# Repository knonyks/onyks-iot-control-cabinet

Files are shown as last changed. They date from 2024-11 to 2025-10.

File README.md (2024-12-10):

# Onyks IoT Control Cabinet

## Description

This device is part of the IoT project, which this part functions as locker for the cabins.
The devices is equiped with RFID MIFARE detector which detects student ID cards, it also has Wi-fi and Bletooth connection for database access.

## Features
* Two ways of power supply:
    - Terminal block;
    - DC Jack;
* Access for JTAG I/O ports;
* Access for programmer I/O ports;
* GPIO ports with GND;
* A buzzer turns on when the cabinet opens;
* An external header for an NFC external sensor by SPI transmission;
* An LED diod;
* Boot and Reset buttons;
* An external input for open the lock by e.g an external button;
* A button for opening the lock;
* Two ways of connecting the lock
    - a pin header;
    - terminal block;
* The voltage which is on the lock I/O port is like the power supply input voltage, e.g. when we have 12 V supply we have 12 V on the lock I/O ports;
* M6 screw holes to mounting.

Teorically when we have:
* 12 V, 2A (24 W) power supply we can power the lock which need 12 V and 1.2 A;
* 9 V, 2 A (18 W) power supply we can power the lock which need 9 V and 1 A;
* If the buzzer was replaced with higher voltage buzzer, then the device can operate with 24 V, 1 A (24 W) power supply;

* Used buzzer voltage range : 6 V - 18 V.

### Schematic

[[LINK]](docs/schematics.pdf)

## Images

#### Connection schematic with an external NFC module
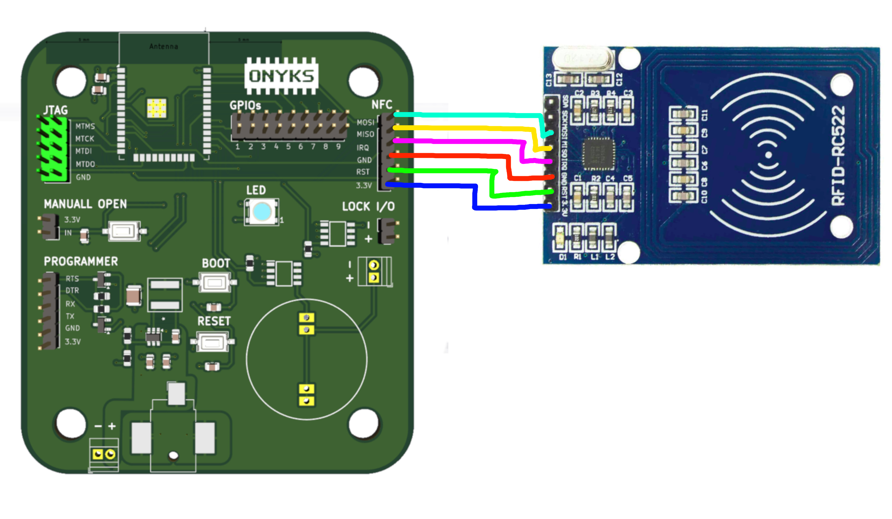
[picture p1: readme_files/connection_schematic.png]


### PCB

#### PCB View
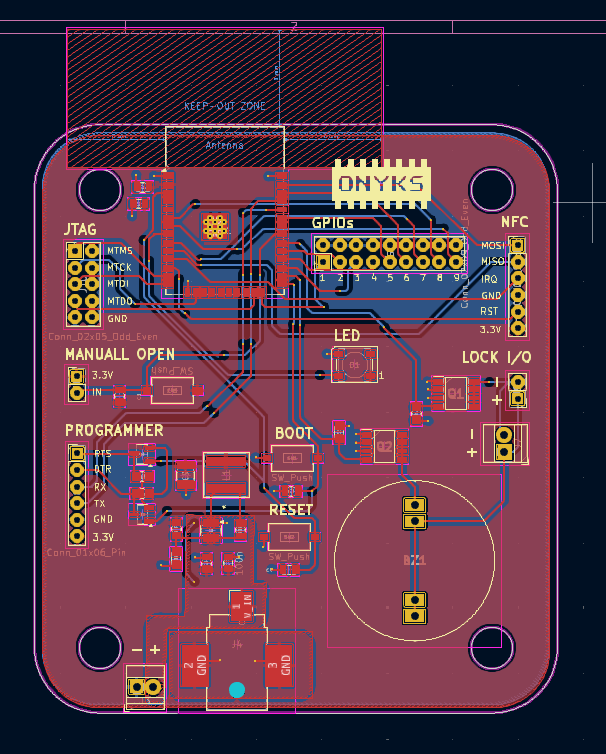
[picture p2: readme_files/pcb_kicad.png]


#### 3D View
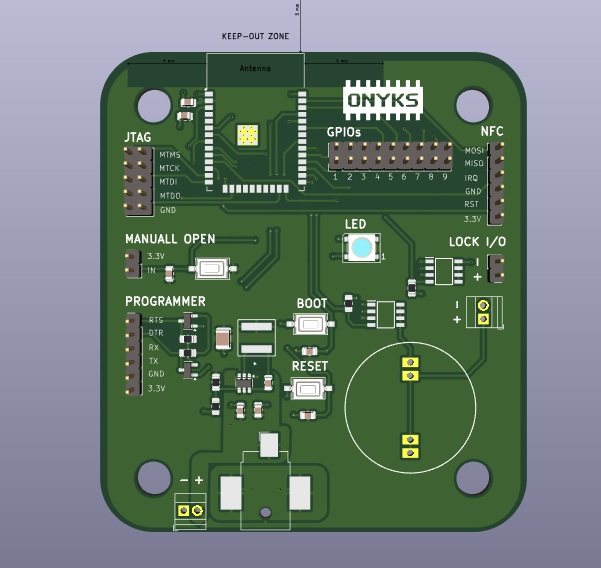
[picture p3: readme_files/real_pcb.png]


## Authors
* Karol Ambroziński
* Jakub Jastrzębski

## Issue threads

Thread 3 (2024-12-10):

Skończone PCB?

zero-jedynkowy, 2024-12-10:
Skończylismy PCB - oddajemy do akceptacji; wyjasnienie PCB jest w README.md.

Koszyk z ,,dzikimi elementami'' - terminal blocki, elementy do przetwornicy, mosfety, buzzer i power jack

 https://www.mouser.pl/ProjectManager/ProjectDetail.aspx?AccessID=6f0a09b32a

----

@zero-jedynkowy  @Xenon02 @przemech

Closed 2025-02-06.

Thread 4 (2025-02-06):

Skończone ale tak naprawde skończone pcb???

zero-jedynkowy, 2025-02-06:
Chyba skończyliśmy ostatecznie?

Poprawiliśmy:
* JTAG jest taki sam w zasadzie jak w ESP PROG (rysunek poniżej)

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
https://docs.espressif.com/projects/esp-iot-solution/en/latest/hw-reference/ESP-Prog_guide.html

* zmiana linii zasilania z poligonu 3.3V na ścieżki - teraz oba poligony na obydwu warstwach są GND
* dodanie rulsów - w drc wyskakują tylko przelotki te od esp
* dodaliśmy wybór zasilania pomiędzy śrubowym a DC jack - jeśli nie zewrzemy ani jacka, ani terminal blocku to możemy z JTAGa zasilanie brać; dzięki zworce nie zewrzemy 3.3V z zasilania z 3.3v JTAGa

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

@przemech @zero-jedynkowy @Xenon02

przemech, 2025-02-10:
Dzięki za informację, dzisiaj sprawdzam i dam znać

przemech, 2025-02-11:
Płytka zdecydowanie zaliczyła duży progres. Proponuję jednakże zrobić spotkanie np. w czwartek? To pokażę jeszcze kilka drobnych problemów.

zero-jedynkowy, 2025-02-17:
Zmiany:
* dodano przelotki na całym PCB;
* zmieniono termal reliefy;
* posprzątano repo.

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

Rulsy:

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

Dodatkowe błędy na dole pod błędami od przelotek z ESP związane z rulsami:
* min. liczbą łącz termicznych.

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

Closed 2025-03-17.

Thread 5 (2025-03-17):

Duże review

przemech, 2025-03-17:
Uniwersalne uwagi - checklist:

- [x] [Hierarchiczna struktura schematu](https://docs.kicad.org/master/en/eeschema/eeschema.html#hierarchical-schematics)
- [x] Global Label -> Net Label (lokalne)
- [x] Global Label -> Hierarchical Label (między schematami)
- [x] No Connect Flags dla niepodłączoncych pinów
- [x] Czytanie schematów od lewej do prawej -> np. zasilanie po lewej i odbiorca po prawej
- [x] Zbyt dokładne wartości elementów (zbyt dokładny szereg)
- [x] Nazwa modelu cewki do symbolu  jako kolejny field
- [x] Napięcia przy kondensatorach np. 10u -> 10n/10V
- [x] Obudowy SMD 0603 (ew. dla kondesnatorów o dużych pojemnościach 0805)
- [x] Przy złączu zasilania opis zakresu napięcia i maksymalny prąd

Do tego projektu:

Schemat:
- [x] Uporządkowanie wyprowadzeń do innych schematów
- [x] Do wydzielenia poszczególne części (dioda WS2018B, lock, buzzer...)
- [x] wszystko z programowania w jednym miejscu (może nawet razem z ESP32)
- [x] NFC connector nie w schemacie power supply
- [x] Niesprecyzowany model przetwornicy (PFM a FPWM)
- [x] Jaki dokładnie model przetwornicy i dlaczego (do napisania w schemacie)?
    - w jakim trybie
    - jak ten tryb działa
    - wyłączanie - efekt ripple
    - zaznaczyć, że tryb PFM
    - do zweryfikowania prądy na schemacie
    - napisać ile prądu w trybach pracy
- [x] Kondensatory 10V
- [x] Kondesantory 100n - 50V
- [x] Kondensator 100u - bardzo duży - na schemacie nie jest to symbol elektrolitycznego
- [x] Przyciski jak SW3, które mają pracować w trybie z pull-down - do napisania, że będą tak pracować -> informacja dla programisty mikrokontrolera
- [x] MOSFET do sprawdzenia na prądy

PCB:
- [ ] Podkładki pod otwory będą zachaczać o elementy
- [ ] Do przeanalizowania rozmieszczenie elementów i routing

przemech, 2025-04-03:
Zamek zamontowany jest w szafie - możemy zmierzyć prąd zamka w poniedziałek.

Closed 2025-07-15.

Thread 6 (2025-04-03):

Otwory montażowe na schemacie

przemech, 2025-04-03:
Na schemacie jest tak:

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

Nie trzeba dodawać tego do schematu, bo to jest tam niepotrzebne.

Można dodać to bezpośrednio w PCB:
- Jako VIA

albo

- `Place` > `Place Footprints` > `MountingHole_3.2mm_M3_DIN965_Pad_TopBottom`.

Później trzeba wejść w ustawienia padów (górnej oraz dolnej warstwy):

- `Pad Properties` > `General` > `Net name`: `GND` x2

Dodatkowo można wyłączyć "clearance" w ustawieniach footprinta:

- `Footprint Properties` > `Clearance Overrides and Settings` > `Pad connection to zones:` > `Solid`

Wygląda to wtedy tak:

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

Xenon02, 2025-04-04:
Tylko to czy jeszcze jakieś zmiany ?

Robiłem tak, bo w robocie w sumie robili podobnie, ale nie ma problemu to zmienić.

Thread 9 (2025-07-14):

Review

przemech, 2025-07-14:
- [x] Kąty ostre, przykłady:

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

- [x] Połączenie goldpinu do warstwy zasilania do poprawy - za cienkie, a przecież ścieżka jest znacznie grubsza:

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

- [x] C11 i C10 do zamiany miejscami i na schemacie i na PCB - mniejsza pojemność bliżej MCU

Closed 2025-07-15.

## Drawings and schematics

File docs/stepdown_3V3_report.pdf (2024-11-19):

## WEBENCH ® Design Report

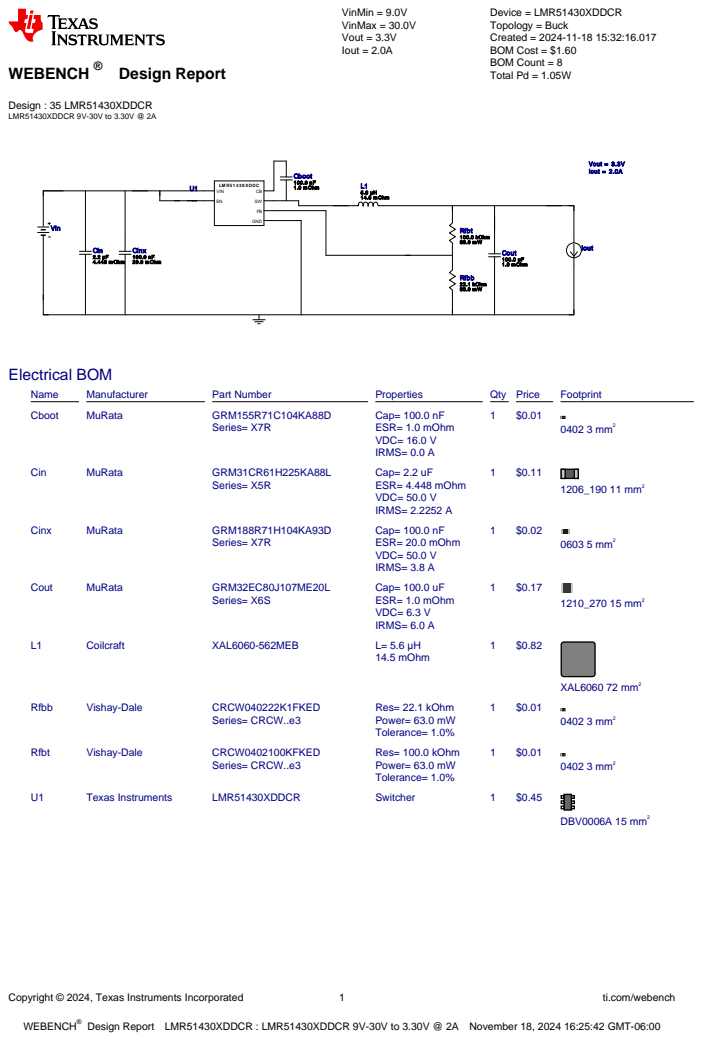
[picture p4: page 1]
Copyright © 2024, Texas Instruments Incorporated; ti.com/webench; WEBENCH®; Design : 35 LMR51430XDDCR LMR51430XDDCR 9V-30V to 3.30V @ 2A; VinMin = 9.0V VinMax = 30.0V Vout = 3.3V Iout = 2.0A; Device = LMR51430XDDCR Topology = Buck Created = 2024-11-18 15:32:16.017 BOM Cost = $1.60 BOM Count = 8 Total Pd = 1.05W; Cin 2.2 µF 4.448 m Ohm; LM R5 1 4 3 0 XDDC; GND; VIN; Cout 100.0 µF 1.0 m Ohm; Cinx 100.0 nF 20.0 m Ohm; L1 5.6 µH 14.5 m Ohm; Rfbb 22.1 kOhm 63.0 m W; Rfbt 100.0 kOhm 63.0 m W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

Design Report LMR51430XDDCR : LMR51430XDDCR 9V-30V to 3.30V @ 2A November 18, 2024 16:25:42 GMT-06:00

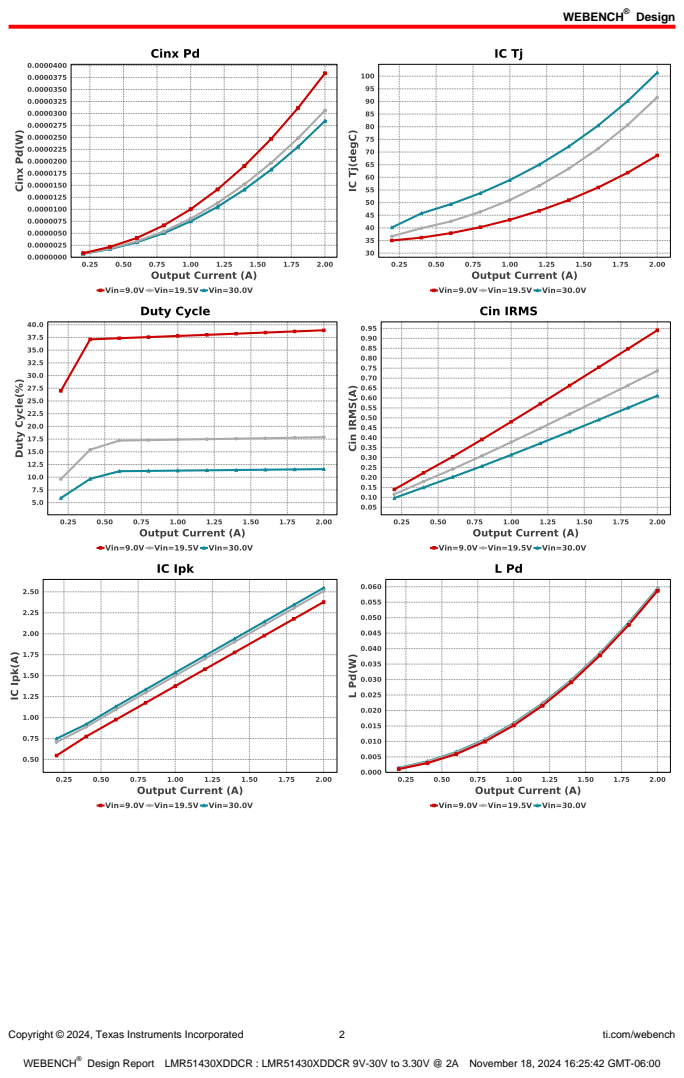
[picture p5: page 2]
Design; Copyright © 2024, Texas Instruments Incorporated; ti.com/webench

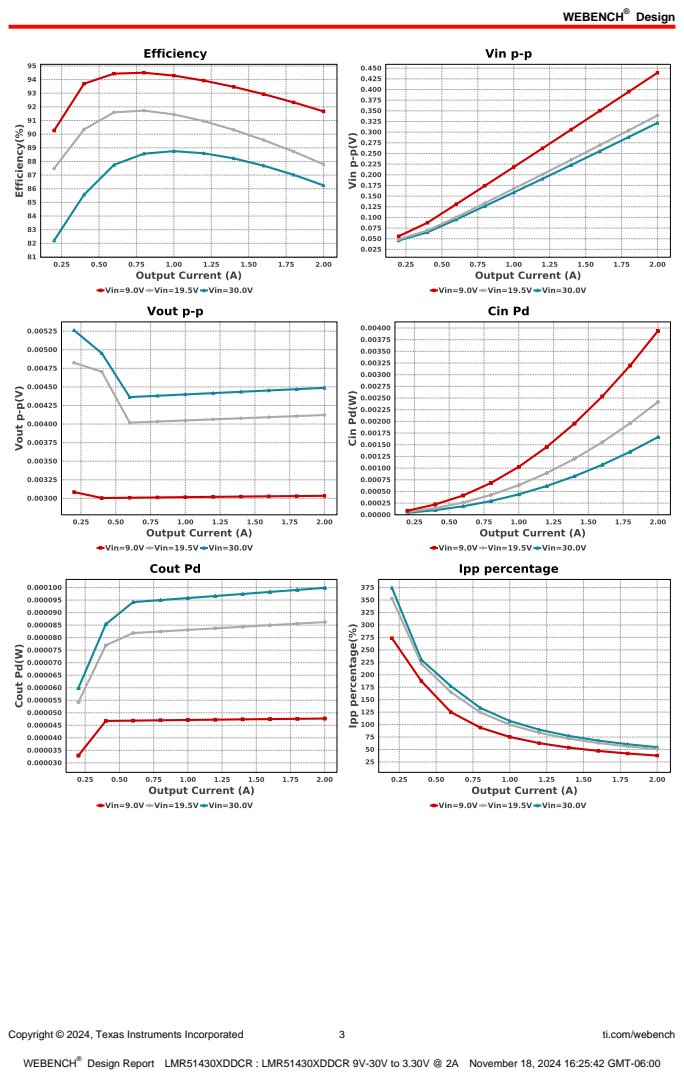
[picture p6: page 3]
Copyright © 2024, Texas Instruments Incorporated; ti.com/webench

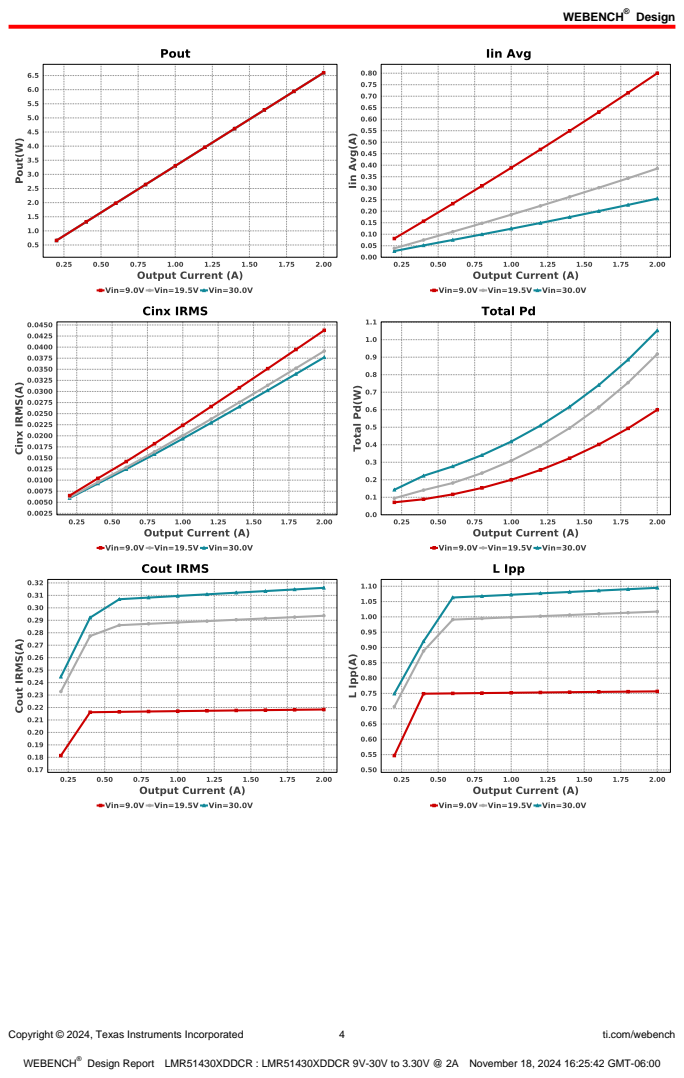
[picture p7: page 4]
Copyright © 2024, Texas Instruments Incorporated; ti.com/webench

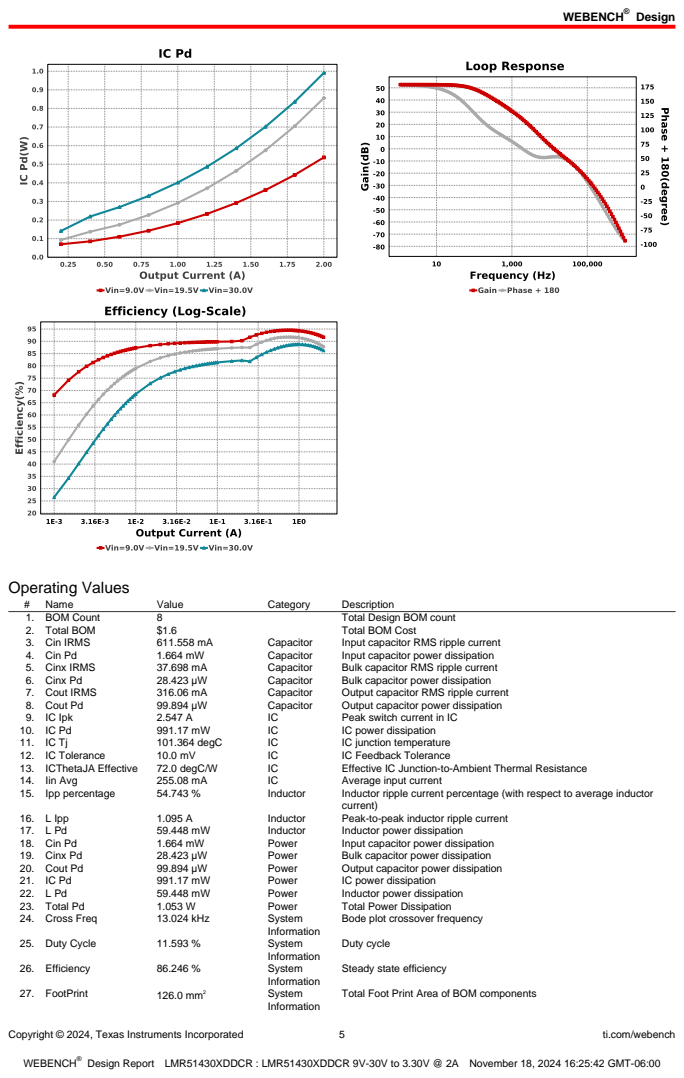
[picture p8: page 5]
Copyright © 2024, Texas Instruments Incorporated; ti.com/webench; Operating Values; Name; Value; Category; Description; 1. BOM Count; Total Design BOM count; 2. Total BOM; Total BOM Cost; 3. Cin IRMS; Capacitor; Input capacitor RMS ripple current; 4. Cin Pd; Input capacitor power dissipation; 5. Cinx IRMS; Bulk capacitor RMS ripple current; 6. Cinx Pd; Bulk capacitor power dissipation; 7. Cout IRMS; Output capacitor RMS ripple current; 8. Cout Pd; Output capacitor power dissipation; 9. IC Ipk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

Bode plot crossover frequency

Steady state efficiency

Total Foot Print Area of BOM components

Copyright © 2024, Texas Instruments Incorporated | 6 | ti.com/webench
# | Name | Value | Category | Description

28. Frequency | 500.0 kHz | System
| | | Information | Switching frequency
29. Gain Marg | -28.074 dB | System
| | | Information | Bode Plot Gain Margin
30. Iout | 2.0 A | System
| | | Information | Iout operating point
31. Low Freq Gain | 52.592 dB | System
| | | Information | Gain at 1Hz
32. Mode | CCM | System
| | | Information | Conduction Mode
33. Phase Marg | 53.292 deg | System
| | | Information | Bode Plot Phase Margin
34. Pout | 6.6 W | System
| | | Information | Total output power
35. Vin | 30.0 V | System
| | | Information | Vin operating point
36. Vin p-p | 321.692 mV | System
| | | Information | Peak-to-peak input voltage
37. Vout | 3.3 V | System
| | | Information | Operational Output Voltage
38. Vout Actual | 3.315 V | System
| | | Information | Vout Actual calculated based on selected voltage divider resistors
39. Vout Tolerance | 3.349 % | System
| | | Information | Vout Tolerance based on IC Tolerance (no load) and voltage divider resistors if applicable
40. Vout p-p | 4.488 mV | System
| | | Information | Peak-to-peak output ripple voltage

## Design Inputs

Name | Value | Description
Iout | 2.0 | Maximum Output Current
VinMax | 30.0 | Maximum input voltage
VinMin | 9.0 | Minimum input voltage
Vout | 3.3 | Output Voltage
| base_pn | | LMR51430X | Base Product Number
source | DC | Input Source Type
Ta | 30.0 | Ambient temperature


Copyright © 2024, Texas Instruments Incorporated | 7 | ti.com/webench

## Assembly

## Component Testing

Some published data on components in datasheets such as Capacitor ESR and Inductor DC resistance is based on conservative values that will guarantee that the components always exceed the specification. For design purposes it is usually better to work with typical values. Since this data is not always available it is a good practice to measure the Capacitance and ESR values of Cin and Cout, and the inductance and DC resistance of L1 before assembly of the board. Any large discrepancies in values should be electrically simulated in WEBENCH to check for instabilities and thermally simulated in WebTHERM to make sure critical temperatures are not exceeded.
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

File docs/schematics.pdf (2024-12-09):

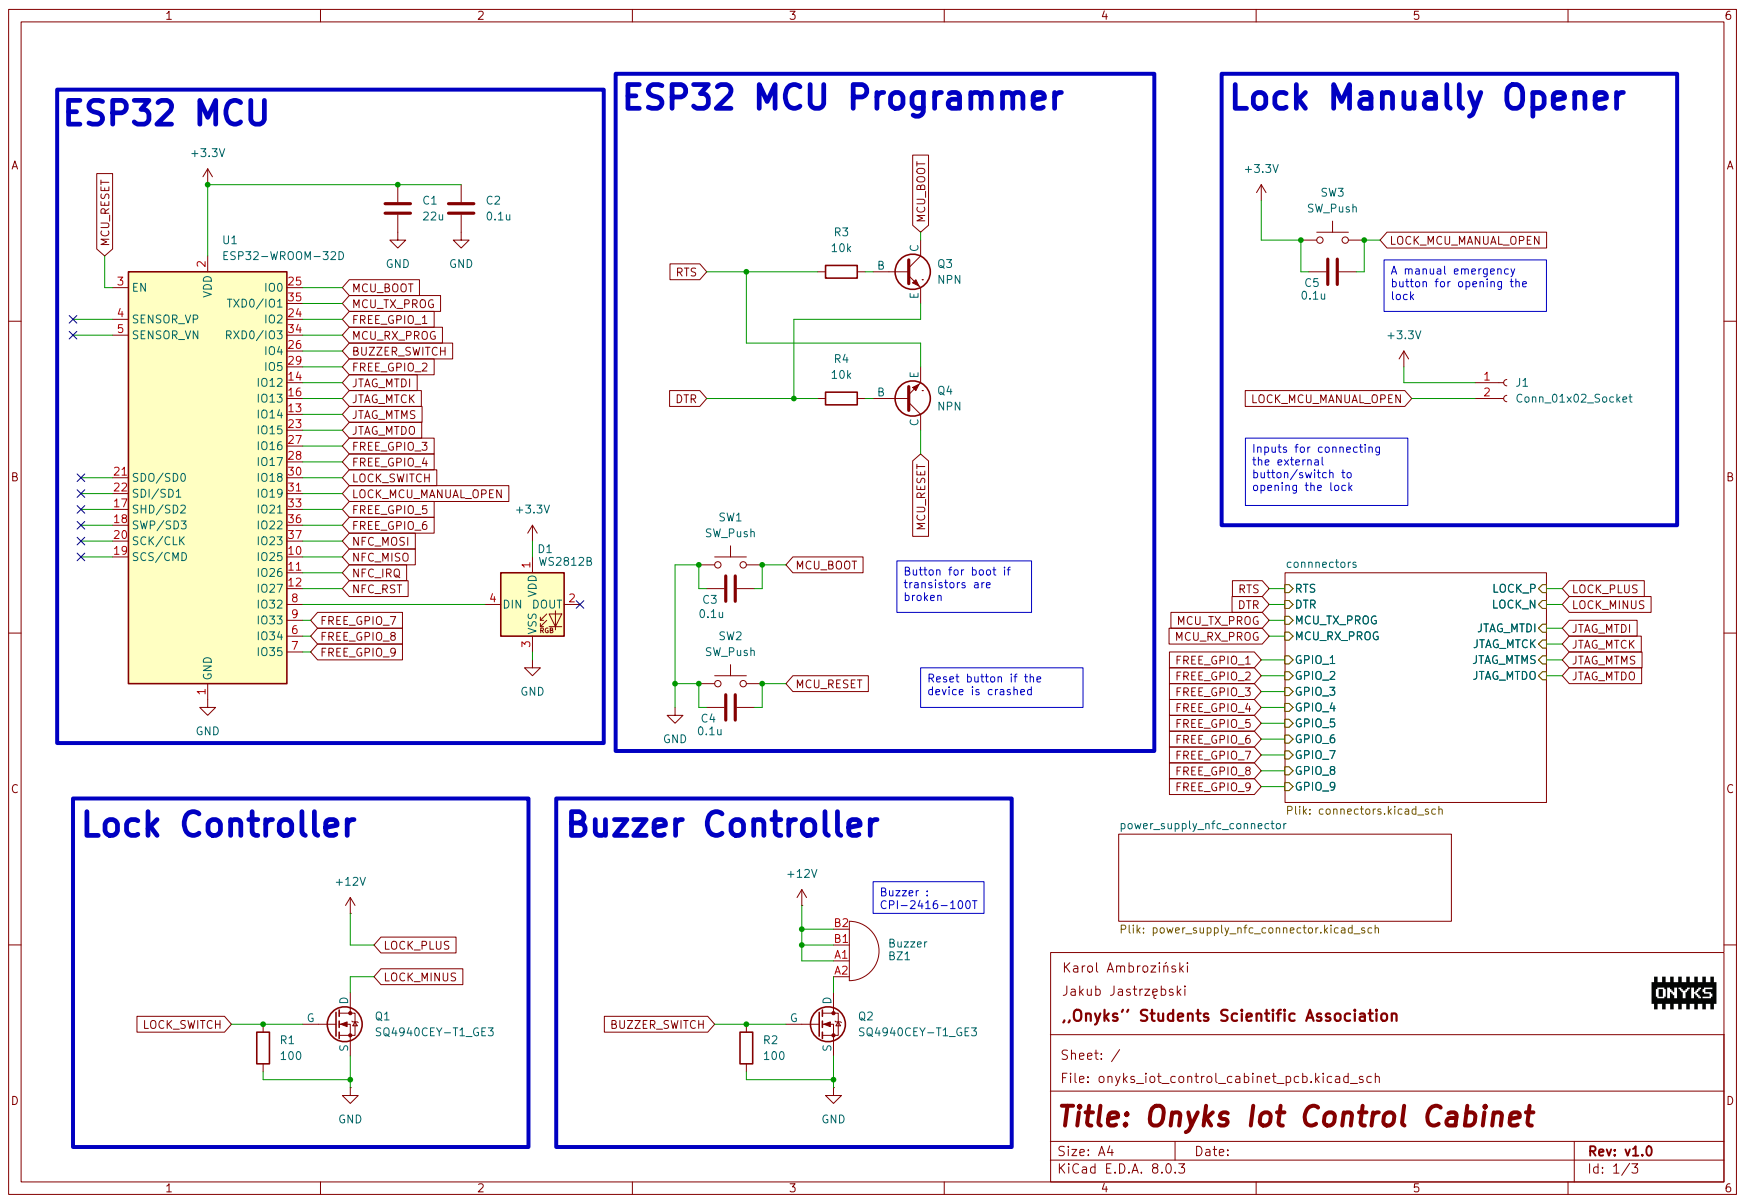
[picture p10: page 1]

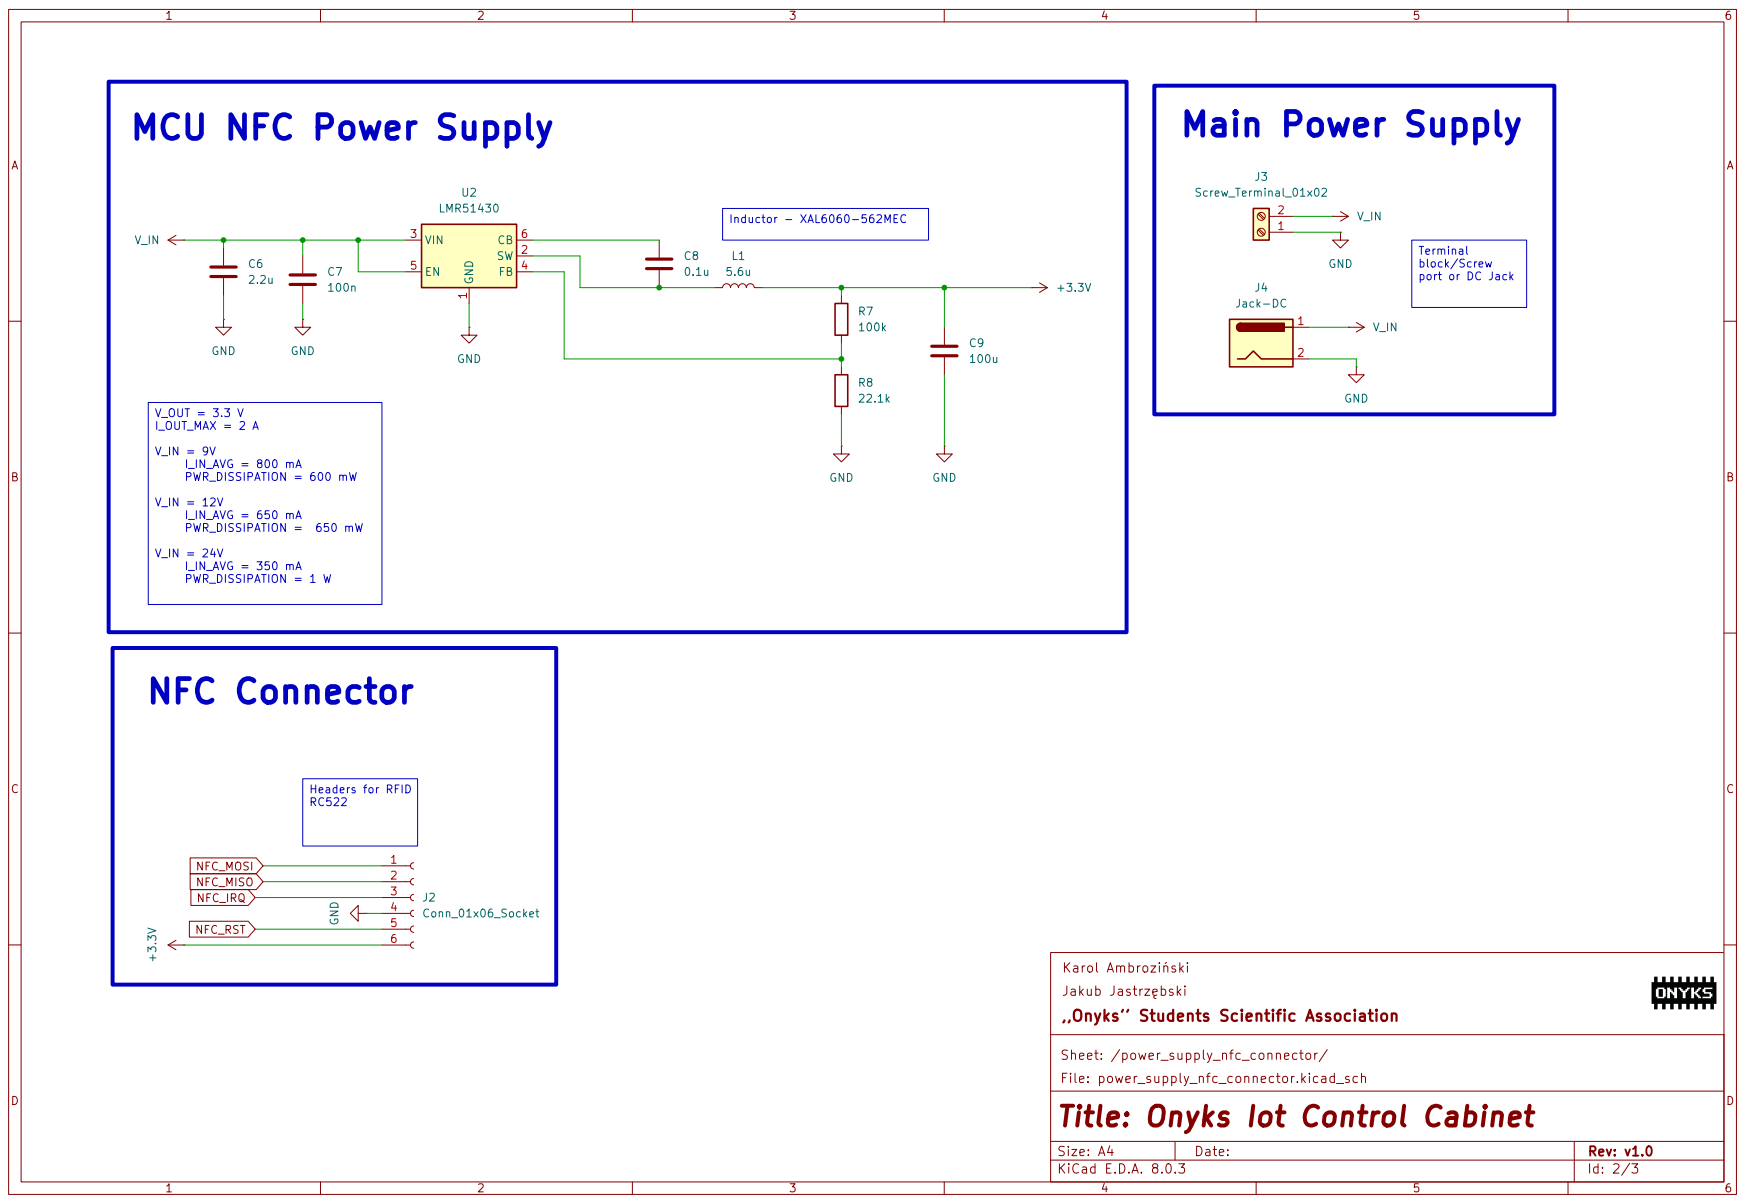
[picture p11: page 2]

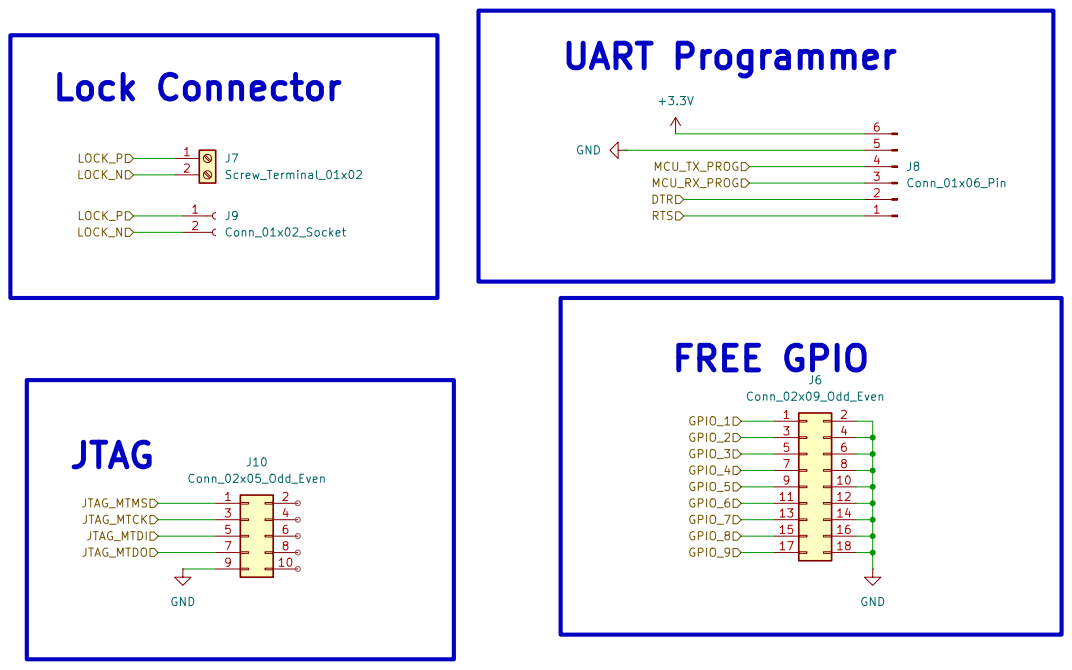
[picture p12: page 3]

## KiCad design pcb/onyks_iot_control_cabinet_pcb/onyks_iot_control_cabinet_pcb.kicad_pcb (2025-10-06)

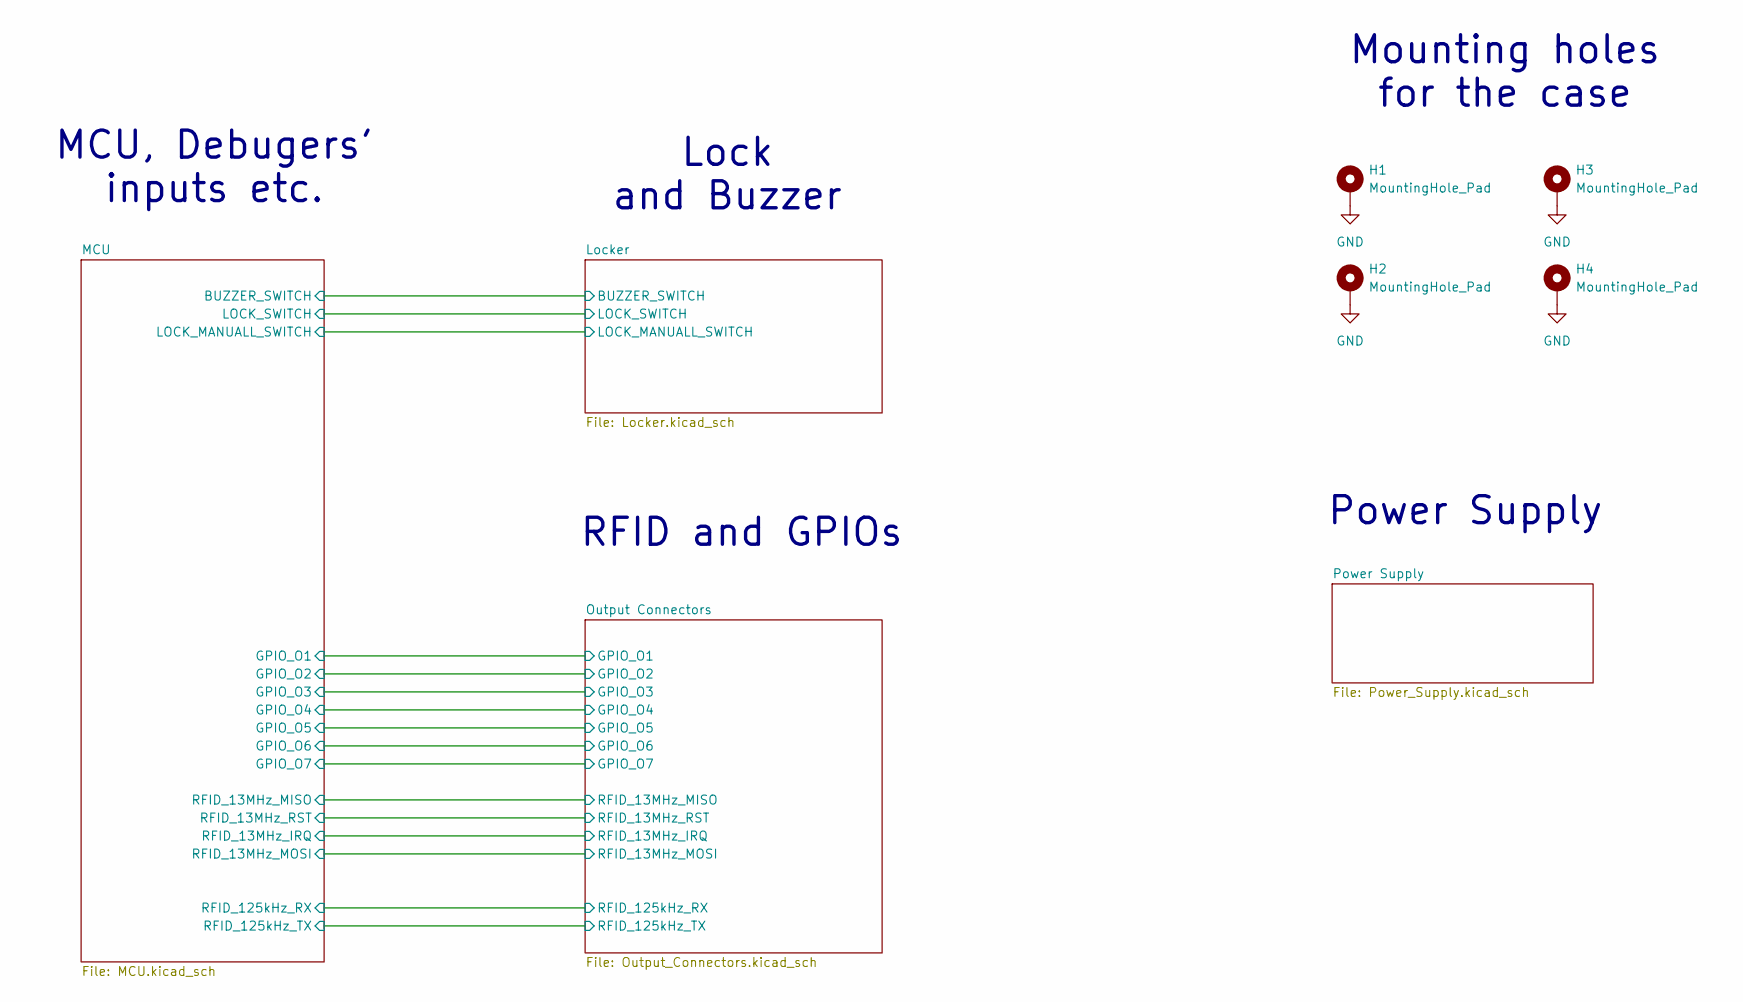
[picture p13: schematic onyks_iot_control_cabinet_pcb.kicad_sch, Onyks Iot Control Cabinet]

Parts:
H1, H2, H3, H4: MountingHole_Pad; MountingHole_3.2mm_M3_DIN965_Pad_TopBottom

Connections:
GND: H1.1, H2.1, H3.1, H4.1; also elsewhere on the board

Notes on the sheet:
Power Supply
RFID and GPIOs
Mounting holes for the case
MCU, Debugers' inputs etc.
Lock and Buzzer

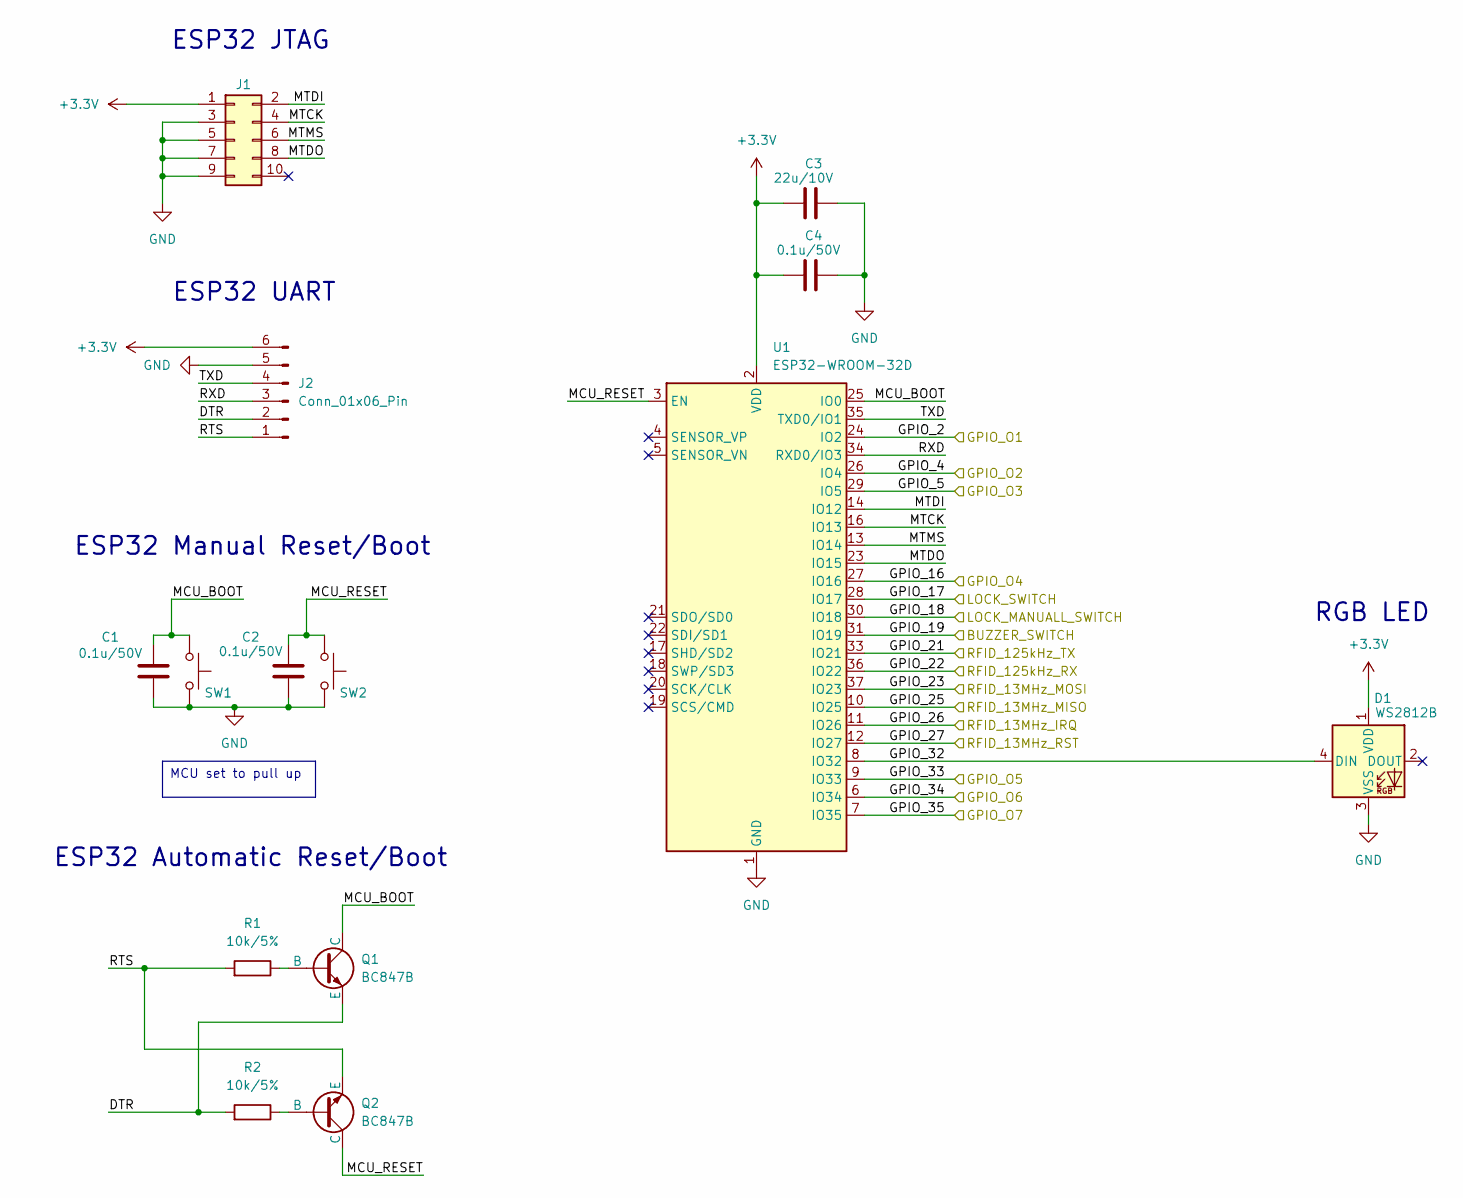
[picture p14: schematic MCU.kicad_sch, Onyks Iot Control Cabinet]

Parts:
C1, C2, C4: 0.1u/50V; C_0603_1608Metric
C3: 22u/10V; C_0603_1608Metric
D1: WS2812B; LED_WS2812B_PLCC4_5.0x5.0mm_P3.2mm
J1: Conn_02x05_Odd_Even; PinHeader_2x05_P2.54mm_Vertical
J2: Conn_01x06_Pin; PinHeader_1x06_P2.54mm_Vertical
Q1, Q2: BC847B; SOT-23-3
R1, R2: 10k/5%; R_0805_2012Metric_Pad1.20x1.40mm_HandSolder
SW1, SW2: SW_Push; SW_Tactile_SPST_NO_Straight_CK_PTS636Sx25SMTRLFS
U1: ESP32-WROOM-32D

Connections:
+3.3V: C3.1, C4.1, D1.1 (VDD), J1.1, J2.6, U1.2 (VDD); also elsewhere on the board
/MCU/DTR: J2.2, Q1.3 (E), R2.2
/MCU/GPIO_2: U1.24 (IO2); also elsewhere on the board
/MCU/GPIO_4: U1.26 (IO4); also elsewhere on the board
/MCU/GPIO_5: U1.29 (IO5); also elsewhere on the board
/MCU/GPIO_16: U1.27 (IO16); also elsewhere on the board
/MCU/GPIO_17: U1.28 (IO17); also elsewhere on the board
/MCU/GPIO_18: U1.30 (IO18); also elsewhere on the board
/MCU/GPIO_19: U1.31 (IO19); also elsewhere on the board
/MCU/GPIO_21: U1.33 (IO21); also elsewhere on the board
/MCU/GPIO_22: U1.36 (IO22); also elsewhere on the board
/MCU/GPIO_23: U1.37 (IO23); also elsewhere on the board
/MCU/GPIO_25: U1.10 (IO25); also elsewhere on the board
/MCU/GPIO_26: U1.11 (IO26); also elsewhere on the board
/MCU/GPIO_27: U1.12 (IO27); also elsewhere on the board
/MCU/GPIO_32: D1.4 (DIN), U1.8 (IO32)
/MCU/GPIO_33: U1.9 (IO33); also elsewhere on the board
/MCU/GPIO_34: U1.6 (IO34); also elsewhere on the board
/MCU/GPIO_35: U1.7 (IO35); also elsewhere on the board
/MCU/MCU_BOOT: C1.1, Q1.1 (C), SW1.1, U1.25 (IO0)
/MCU/MCU_RESET: C2.1, Q2.1 (C), SW2.1, U1.3 (EN)
/MCU/MTCK: J1.4, U1.16 (IO13)
/MCU/MTDI: J1.2, U1.14 (IO12)
/MCU/MTDO: J1.8, U1.23 (IO15)
/MCU/MTMS: J1.6, U1.13 (IO14)
/MCU/RTS: J2.1, Q2.3 (E), R1.2
/MCU/RXD: J2.3, U1.34 (RXD0/IO3)
/MCU/TXD: J2.4, U1.35 (TXD0/IO1)
GND: C1.2, C2.2, C3.2, C4.2, D1.3 (VSS), J1.3, J1.5, J1.7, J1.9, J2.5, SW1.2, SW2.2, U1.1 (GND), U1.15 (GND), U1.38 (GND), U1.39 (GND); also elsewhere on the board
unnamed: Q1.2 (B), R1.1
unnamed: Q2.2 (B), R2.1

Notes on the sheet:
ESP32 UART
RGB LED
ESP32 Automatic Reset/Boot
ESP32 Manual Reset/Boot
ESP32 JTAG
MCU set to pull up

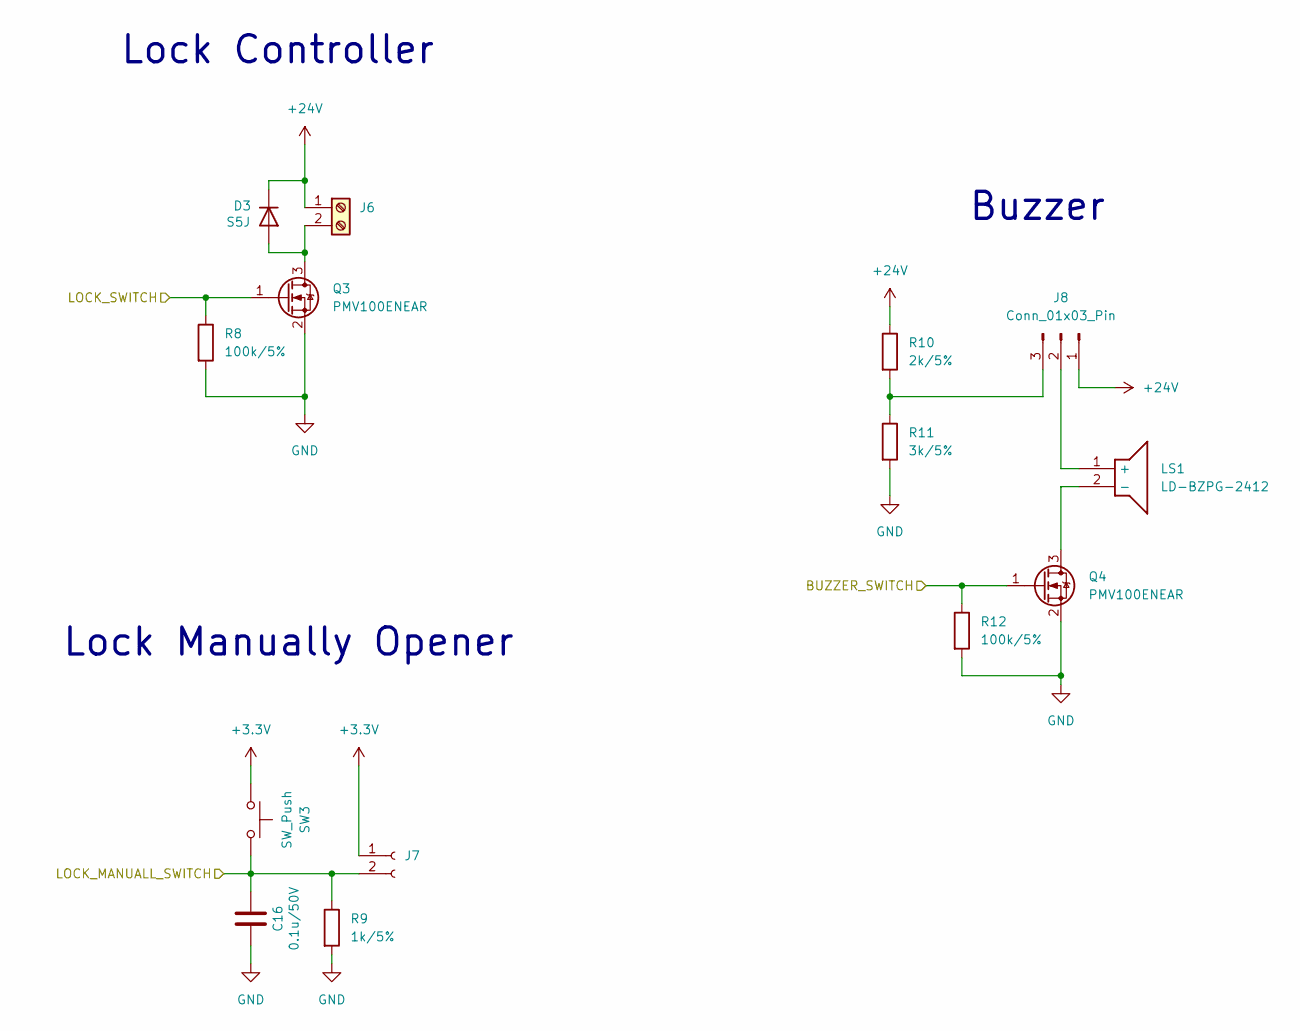
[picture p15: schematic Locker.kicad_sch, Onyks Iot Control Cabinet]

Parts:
C16: 0.1u/50V; C_0603_1608Metric
D3: S5J; D_SMC
J6: Screw_Terminal_01x02; TerminalBlock_Altech_AK300-2_P5.00mm
J7: Conn_01x02_Socket; PinHeader_1x02_P2.54mm_Vertical
J8: Conn_01x03_Pin; PinHeader_1x03_P2.54mm_Vertical
LS1: LD-BZPG-2412; LDBZPG2412; Manufacturer_Part_Number LD-BZPG-2412
Q3, Q4: PMV100ENEAR; SOT-23
R8, R12: 100k/5%; R_0805_2012Metric_Pad1.20x1.40mm_HandSolder
R9: 1k/5%; R_0805_2012Metric_Pad1.20x1.40mm_HandSolder
R10: 2k/5%; R_0805_2012Metric_Pad1.20x1.40mm_HandSolder
R11: 3k/5%; R_0805_2012Metric_Pad1.20x1.40mm_HandSolder
SW3: SW_Push; SW_Tactile_SPST_NO_Straight_CK_PTS636Sx25SMTRLFS

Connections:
+3.3V: J7.1, SW3.1; also elsewhere on the board
+24V: D3.1 (K), J6.1, J8.1, R10.1; also elsewhere on the board
/MCU/GPIO_17: Q3.1 (G), R8.1; also elsewhere on the board
/MCU/GPIO_18: C16.1, J7.2, R9.1, SW3.2; also elsewhere on the board
/MCU/GPIO_19: Q4.1 (G), R12.1; also elsewhere on the board
GND: C16.2, Q3.2 (S), Q4.2 (S), R8.2, R9.2, R11.2, R12.2; also elsewhere on the board
unnamed: D3.2 (A), J6.2, Q3.3 (D)
unnamed: J8.2, LS1.1 (+)
unnamed: J8.3, R10.2, R11.1
unnamed: LS1.2 (-), Q4.3 (D)

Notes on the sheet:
Lock Manually Opener
Lock Controller
Buzzer

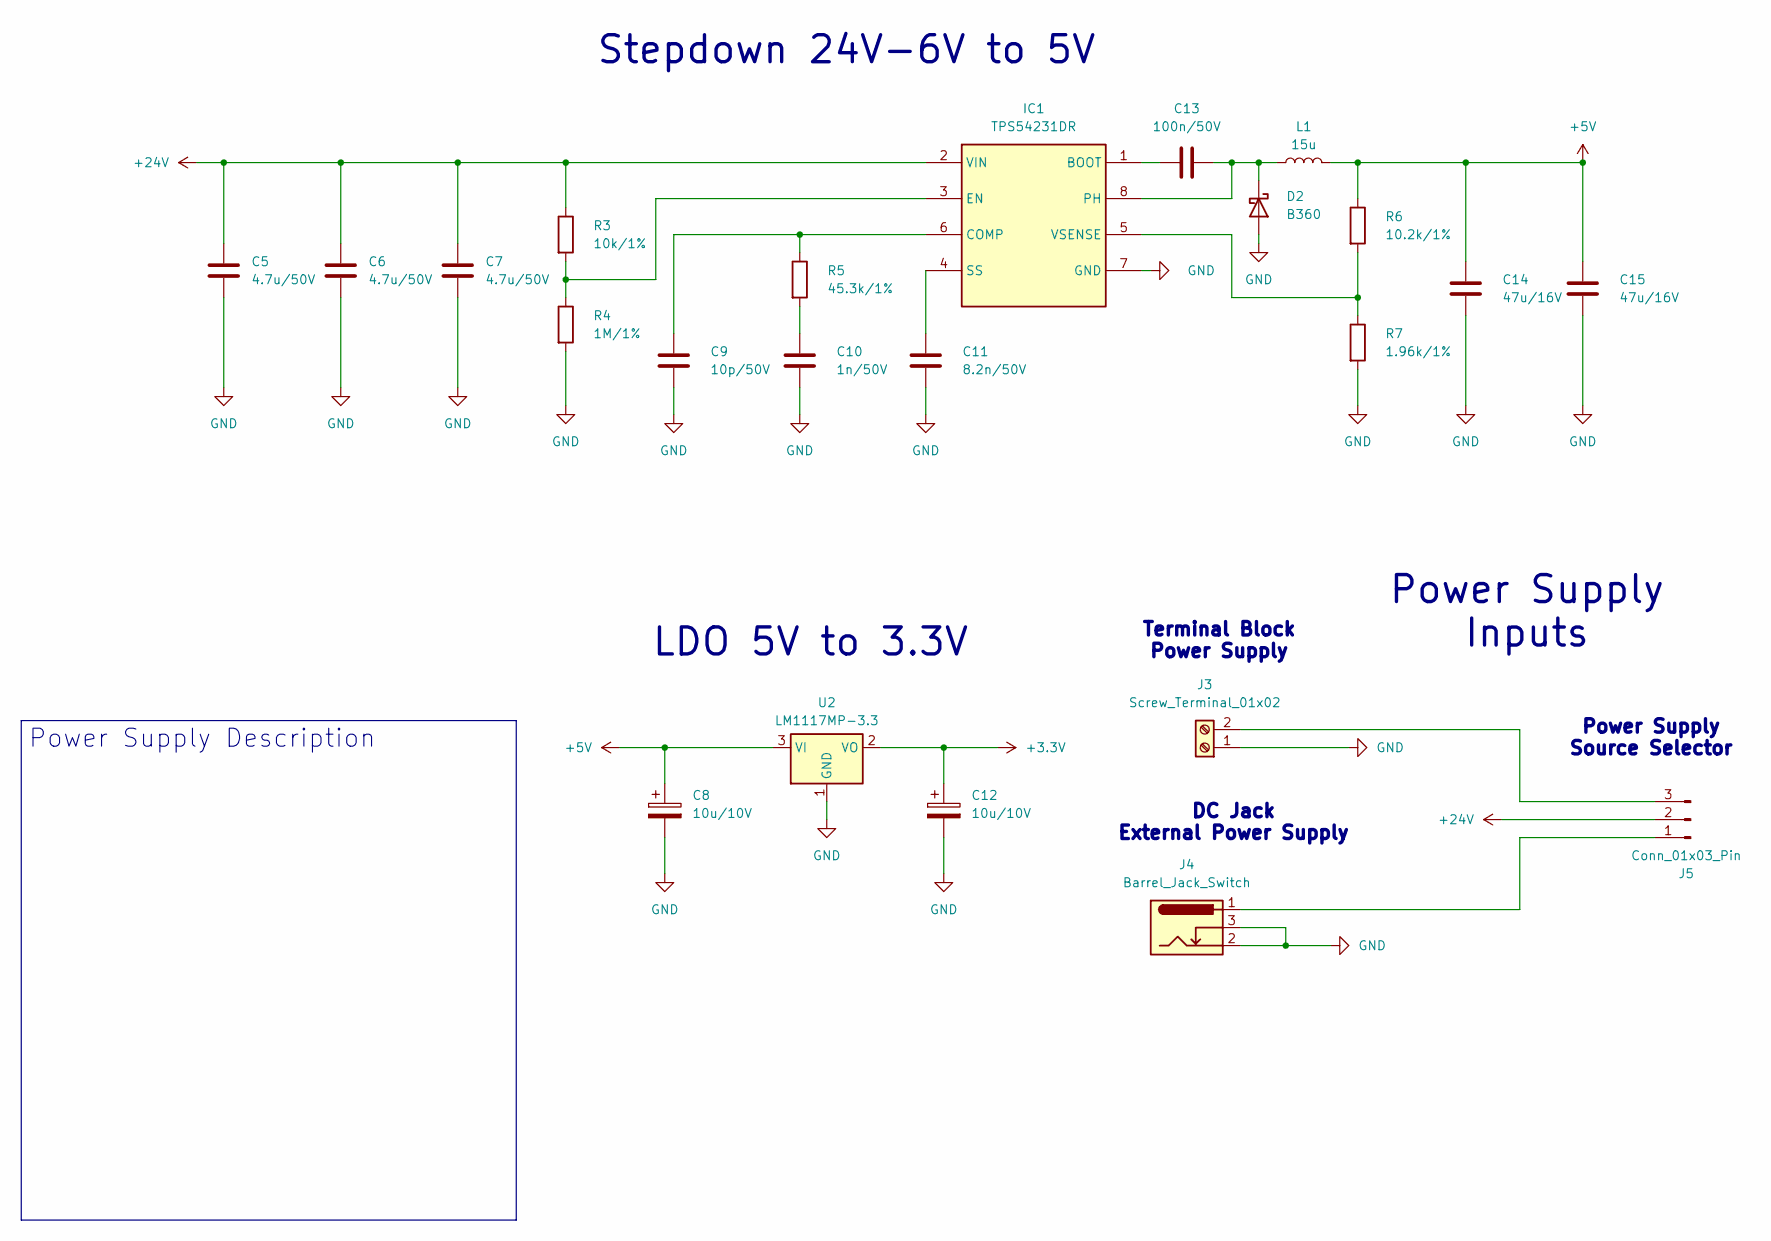
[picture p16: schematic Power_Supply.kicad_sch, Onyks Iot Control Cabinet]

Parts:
C5, C6, C7: 4.7u/50V; C_0603_1608Metric
C8, C12: 10u/10V; C_0603_1608Metric
C9: 10p/50V; C_0603_1608Metric
C10: 1n/50V; C_0603_1608Metric
C11: 8.2n/50V; C_0603_1608Metric
C13: 100n/50V; C_0603_1608Metric
C14, C15: 47u/16V; C_0603_1608Metric
D2: B360; D_SMC
IC1: TPS54231DR; SOIC127P600X175-8N; Manufacturer_Part_Number TPS54231DR
J3: Screw_Terminal_01x02; TerminalBlock_Altech_AK300-2_P5.00mm
J4: Barrel_Jack_Switch; BarrelJack_CLIFF_FC681465S_SMT_Horizontal
J5: Conn_01x03_Pin; PinHeader_1x03_P2.54mm_Vertical
L1: 15u; L_12x12mm_H4.5mm
R3: 10k/1%; R_0805_2012Metric_Pad1.20x1.40mm_HandSolder
R4: 1M/1%; R_0805_2012Metric_Pad1.20x1.40mm_HandSolder
R5: 45.3k/1%; R_0805_2012Metric_Pad1.20x1.40mm_HandSolder
R6: 10.2k/1%; R_0805_2012Metric_Pad1.20x1.40mm_HandSolder
R7: 1.96k/1%; R_0805_2012Metric_Pad1.20x1.40mm_HandSolder
U2: LM1117MP-3.3; SOT-223-3_TabPin2

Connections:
+3.3V: C12.1, U2.2 (VO); also elsewhere on the board
+5V: C8.1, C14.1, C15.1, L1.2, R6.1, U2.3 (VI); also elsewhere on the board
+24V: C5.1, C6.1, C7.1, IC1.2 (VIN), J5.2, R3.1; also elsewhere on the board
GND: C5.2, C6.2, C7.2, C8.2, C9.2, C10.2, C11.2, C12.2, C14.2, C15.2, D2.2 (A), IC1.7 (GND), J3.1, J4.2, J4.3, R4.2, R7.2, U2.1 (GND); also elsewhere on the board
unnamed: C10.1, R5.2
unnamed: C13.2, D2.1 (K), IC1.8 (PH), L1.1
unnamed: C13.1, IC1.1 (BOOT)
unnamed: C9.1, IC1.6 (COMP), R5.1
unnamed: IC1.3 (EN), R3.2, R4.1
unnamed: C11.1, IC1.4 (SS)
unnamed: IC1.5 (VSENSE), R6.2, R7.1
unnamed: J3.2, J5.3
unnamed: J4.1, J5.1

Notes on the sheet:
DC Jack External Power Supply
LDO 5V to 3.3V
Stepdown 24V-6V to 5V
Power Supply Source Selector
Terminal Block Power Supply
Power Supply Inputs
Power Supply Description

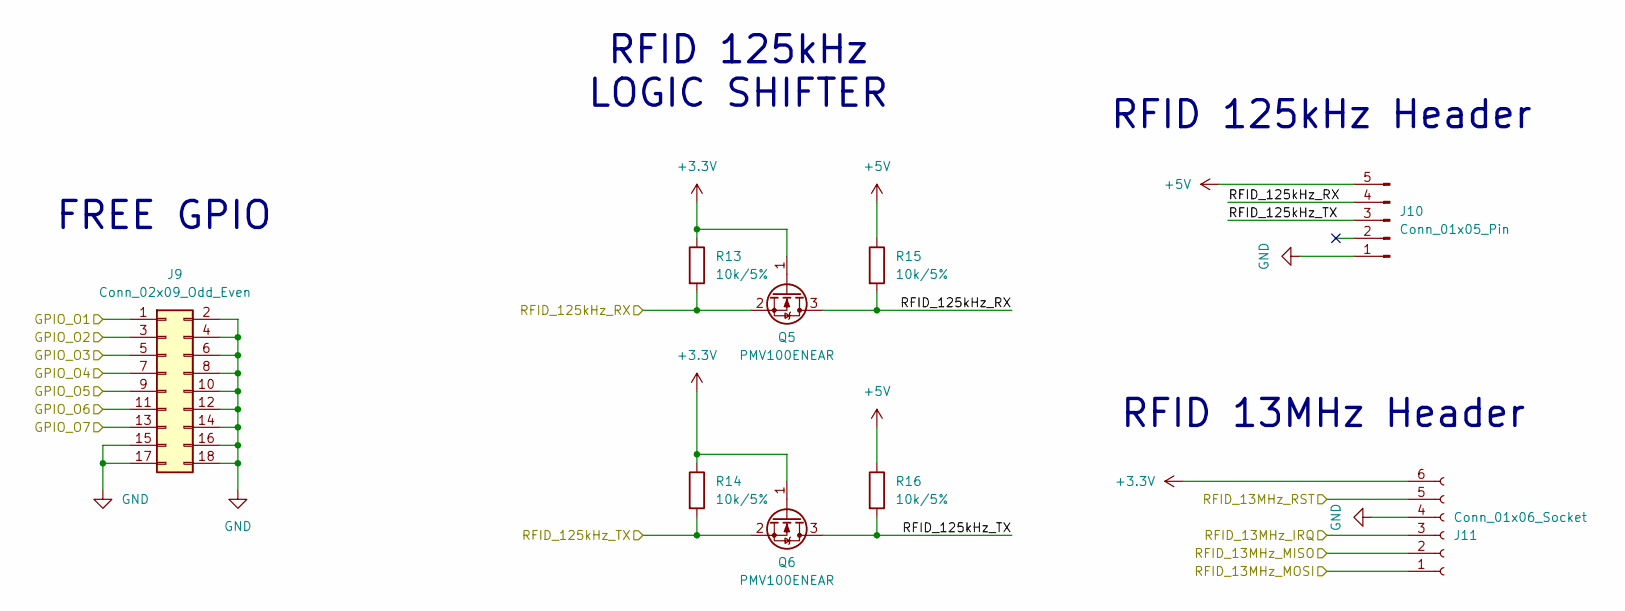
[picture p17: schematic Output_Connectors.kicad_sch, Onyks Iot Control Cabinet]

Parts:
J9: Conn_02x09_Odd_Even; PinHeader_2x09_P2.54mm_Vertical
J10: Conn_01x05_Pin; PinHeader_1x05_P2.54mm_Vertical
J11: Conn_01x06_Socket; PinHeader_1x06_P2.54mm_Vertical
Q5, Q6: PMV100ENEAR; SOT-23
R13, R14, R15, R16: 10k/5%; R_0805_2012Metric_Pad1.20x1.40mm_HandSolder

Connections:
+3.3V: J11.6, Q5.1 (G), Q6.1 (G), R13.1, R14.1; also elsewhere on the board
+5V: J10.5, R15.1, R16.1; also elsewhere on the board
/MCU/GPIO_2: J9.1; also elsewhere on the board
/MCU/GPIO_4: J9.3; also elsewhere on the board
/MCU/GPIO_5: J9.5; also elsewhere on the board
/MCU/GPIO_16: J9.7; also elsewhere on the board
/MCU/GPIO_21: J10.3, Q6.2 (S), Q6.3 (D), R14.2, R16.2; also elsewhere on the board
/MCU/GPIO_22: J10.4, Q5.2 (S), Q5.3 (D), R13.2, R15.2; also elsewhere on the board
/MCU/GPIO_23: J11.1; also elsewhere on the board
/MCU/GPIO_25: J11.2; also elsewhere on the board
/MCU/GPIO_26: J11.3; also elsewhere on the board
/MCU/GPIO_27: J11.5; also elsewhere on the board
/MCU/GPIO_33: J9.9; also elsewhere on the board
/MCU/GPIO_34: J9.11; also elsewhere on the board
/MCU/GPIO_35: J9.13; also elsewhere on the board
GND: J9.2, J9.4, J9.6, J9.8, J9.10, J9.12, J9.14, J9.15, J9.16, J9.17, J9.18, J10.1, J11.4; also elsewhere on the board

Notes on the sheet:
RFID 125kHz LOGIC SHIFTER
RFID 13MHz Header
RFID 125kHz Header
FREE GPIO

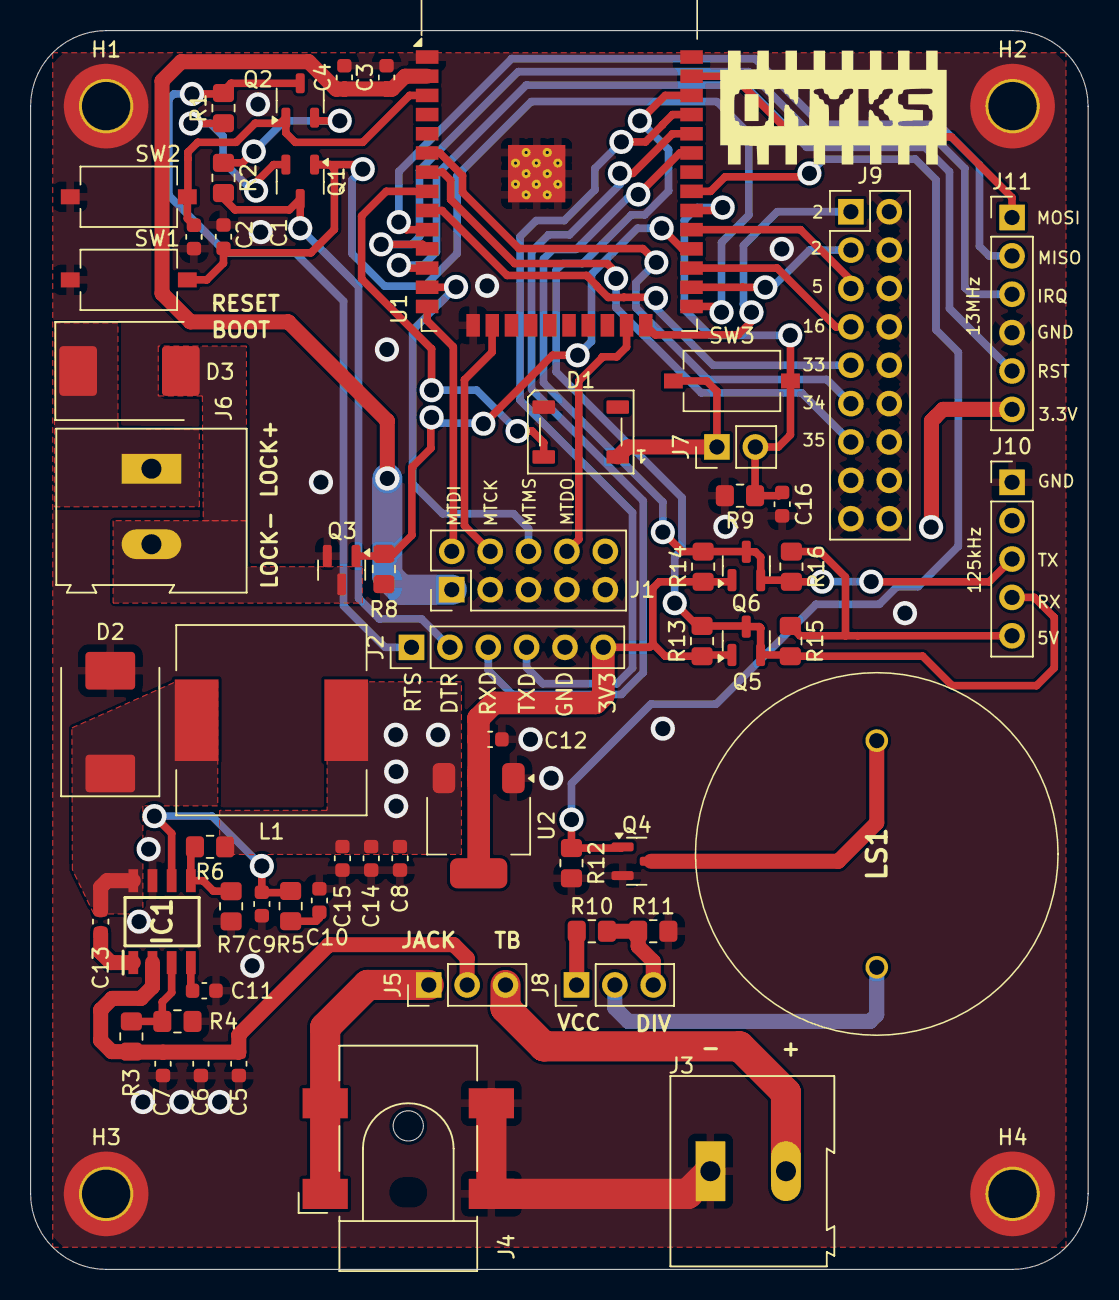
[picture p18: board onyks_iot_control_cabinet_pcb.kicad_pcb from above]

Board: 2 copper layers, 70.0 x 82.0 mm, 64 parts (0 on the bottom side), 46 nets.

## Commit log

2024-11-09 Pierwsze szkice schematu
    [ESP32-Zamek.kicad_pcb, ESP32-Zamek.kicad_sch]
2024-11-10 Poczatki NFC
    [ESP32-Zamek.kicad_sch, nfc.kicad_sch]
2024-11-10 NFC - znaleziono dokumentację projektową xD
    [ESP32-Zamek.kicad_sch, nfc.kicad_sch]
2024-11-16 Booting/Reset circuit change
    [ESP32-Zamek.kicad_sch, nfc.kicad_sch]
2024-11-16 Small changes to the buttons and lock control
    [ESP32-Zamek.kicad_sch, Lock_Control_Cinruit_sch.kicad_sch]
2024-11-17 Add the nfc connector with external outputs
    [ESP32-Zamek.kicad_sch, nfc.kicad_sch]
2024-11-19 Updates of the schematics and add the README.md; add a step-down for 3V3
    [ESP32-Zamek.kicad_sch, power_supply.kicad_sch]
2024-11-19 Fix the folders and files names - Vol. 1
    [ESP32-Zamek.kicad_pcb, ESP32-Zamek.kicad_sch, Lock_Control_Cinruit_sch.kicad_sch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]
2024-11-19 Add a buzzer controller to the schematic
    [ESP32-Zamek.kicad_sch]
2024-11-21 Added Connectors, Fixed buttons
    [Connectors_sch.kicad_sch, ESP32-Zamek.kicad_sch]
2024-11-21 Add one note
    [ESP32-Zamek.kicad_sch, power_supply.kicad_sch]
2024-12-01 Fix the project; cleaning up the things
    [Connectors_sch.kicad_sch, ESP32-Zamek.kicad_pcb, Lock_Control_Cinruit_sch.kicad_sch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]
2024-12-01 Assignment some footprints to symbols
    [connectors.kicad_sch, onyks_iot_control_cabinet_pcb.kicad_sch, power_supply_nfc_connector.kicad_sch]
2024-12-01 PCB - Finished, needs additional confirmation
    [connectors.kicad_sch, onyks_iot_control_cabinet_pcb.kicad_pcb, onyks_iot_control_cabinet_pcb.kicad_sch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]
2024-12-05 Change some elements footprints
    [connectors.kicad_sch, onyks_iot_control_cabinet_pcb.kicad_sch]
2024-12-08 PCB's update
    [onyks_iot_control_cabinet_pcb.kicad_pcb]
2024-12-08 Minor corrections/Rules
    [onyks_iot_control_cabinet_pcb.kicad_pcb]
2024-12-08 Change the connector of GPIOs
    [connectors.kicad_sch]
2024-12-08 Patching GND for Free GPIO Connections
    [connectors.kicad_sch, onyks_iot_control_cabinet_pcb.kicad_pcb]
2024-12-10 Fixed minor mistakes (name of MOS component)
    [onyks_iot_control_cabinet_pcb.kicad_sch]
2025-02-02 Add new rules, change JTAG and VCC polygon plane
    [FlashPCB_DRC_for_KiCad.kicad_pcb, connectors.kicad_sch, onyks_iot_control_cabinet_pcb.kicad_pcb]
2025-02-03 Changed VCC polygon into GND polygon, VCC traces added
    [onyks_iot_control_cabinet_pcb.kicad_pcb]
2025-02-06 Fixing footprint
2025-02-06 Add pins for the jumper and choosing the power supply; also add connection for JTAG 3V3
    [connectors.kicad_sch, onyks_iot_control_cabinet_pcb.kicad_pcb, power_supply_nfc_connector.kicad_sch]
2025-02-14 Adding Thermal Relieves, Via stiching, Components Silkscreen
    [onyks_iot_control_cabinet_pcb.kicad_pcb]
2025-02-17 Onyks - Karol narzekal <3
    [onyks_iot_control_cabinet_pcb.kicad_pcb]
2025-02-17 Almost final fixes of the PCB?
2025-03-05 Adding 3D models
    [Same_Sky_CPI-2416-100T.step, Same_Sky_PJ-036AH-SMT-TR.step, XAL6060-562MEC.stp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]
2025-03-06 Karol can't add mounting holes/Added
    [connectors.kicad_sch, onyks_iot_control_cabinet_pcb.kicad_pcb]
2025-03-14 PCB Update for package
    [connectors.kicad_sch, onyks_iot_control_cabinet_pcb.kicad_pcb]
2025-03-18 Redrawing schematics
    [Locker.kicad_sch, MCU.kicad_sch, Output_Connectors.kicad_sch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]
2025-03-27 New fixes of schematics
    [Locker.kicad_sch, MCU.kicad_sch, Power_Supply.kicad_sch]
2025-03-27 Quick Fixes
    [Locker.kicad_sch, MCU.kicad_sch, Output_Connectors.kicad_sch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]
2025-04-03 Final fixes? - update the power supply
    [Locker.kicad_sch, Power_Supply.kicad_sch]
2025-04-03 Schematic last check
    [Power_Supply.kicad_sch]
2025-06-20 PCB Overhaul
    [Power_Supply.kicad_sch, onyks_iot_control_cabinet_pcb.kicad_pcb]
2025-06-23 Round corners and the logo
    [onyks_iot_control_cabinet_pcb.kicad_pcb]
2025-06-24 Add descriptions to ports
    [onyks_iot_control_cabinet_pcb.kicad_pcb]
2025-06-24 Silkscreen changes
    [onyks_iot_control_cabinet_pcb.kicad_pcb]
2025-07-14 PCB Review 2.0 Update
    [Locker.kicad_sch, MCU.kicad_sch, Output_Connectors.kicad_sch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]
2025-07-15 Update the PCB and schematics; add the potentiometer
    [Locker.kicad_sch, onyks_iot_control_cabinet_pcb.kicad_pcb]
2025-07-23 Update of the power supply; change of the stepdown from 3.3V to 5V on the output without updating the PCB
    [Power_Supply.kicad_sch]
2025-08-26 Update of the power supply and added the header for 125kHz RFID
    [Locker.kicad_sch, MCU.kicad_sch, Output_Connectors.kicad_sch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]
2025-08-26 Logic Shifter for RFID 125 KHz
    [Output_Connectors.kicad_sch]
2025-10-02 Schematics update; power supply and footprints fixes
    [Locker.kicad_sch, MCU.kicad_sch, Output_Connectors.kicad_sch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]
2025-10-02 PCB Ressurection
    [Locker.kicad_sch, MCU.kicad_sch, Output_Connectors.kicad_sch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]
2025-10-02 PCB Update
    [MCU.kicad_sch, Output_Connectors.kicad_sch, onyks_iot_control_cabinet_pcb.kicad_pcb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]
2025-10-04 Updated PCB 2
    [onyks_iot_control_cabinet_pcb.kicad_pcb]
2025-10-06 PCB 3.3V fix
    [onyks_iot_control_cabinet_pcb.kicad_pcb]
2025-10-06 PCB Update 3
    [onyks_iot_control_cabinet_pcb.kicad_pcb]
2025-10-06 PCB descriptions
    [onyks_iot_control_cabinet_pcb.kicad_pcb]
2025-10-26 Gerber files update
    [onyks_iot_control_cabinet_pcb-B_Cu.gbr, onyks_iot_control_cabinet_pcb-B_Mask.gbr, onyks_iot_control_cabinet_pcb-B_Paste.gbr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]

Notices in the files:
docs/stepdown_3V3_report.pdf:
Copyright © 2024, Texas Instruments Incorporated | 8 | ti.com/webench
